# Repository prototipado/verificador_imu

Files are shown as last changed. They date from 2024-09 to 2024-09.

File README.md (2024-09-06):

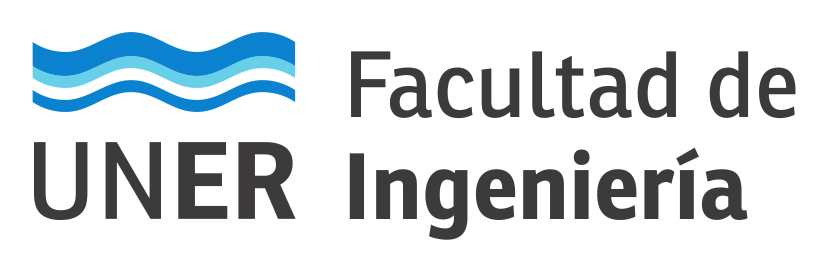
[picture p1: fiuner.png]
Scheme|30%


# Verificación de IMUs

En este repositorio se encuentran los archivos de diseño para un dispositivo destinado a la verificación de IMUs. El diseño se basa en el [Cubo de Calibración](https://github.com/xioTechnologies/Calibration-Cube) propuesto por Madgwick, pero en este caso no se utiliza para calibración, sino para verificar los valores de orientación espacial generados por una IMU a partir de la fusión de datos de sensores inerciales y/o magnetómetros.

El dispositivo tiene dos variantes, una de ellas utilizada para verificaciones estáticas, donde la plataforma se mueve de manera manual siguiendo posiciones preestablecidas cada 5º.

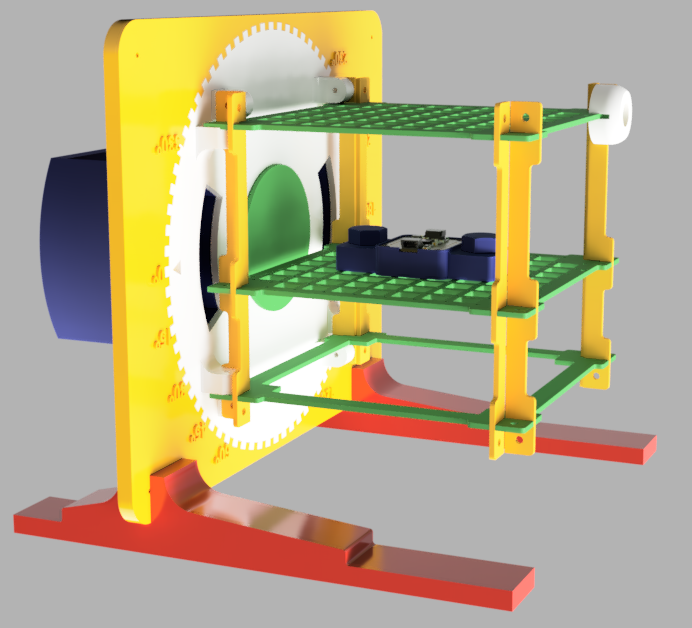
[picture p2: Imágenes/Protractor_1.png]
protractor


Y otra variante donde se monta sobre un servo (MG996R) para verificaciones dinámicas, asistidas por análisis de video.

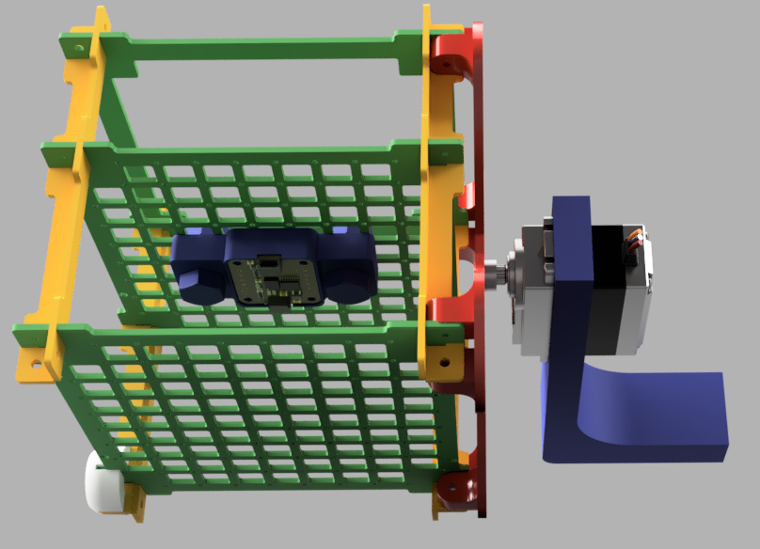
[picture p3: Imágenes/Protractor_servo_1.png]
protractor_servo


## Implementación

El diseño esta pensado para ser impreso en 3D, para la versión estática es necesario imprimir:

| Parte | Cantidad |
| :--- | ---: |
| base | 1 |
| base_completa | 2 |
| pata | 2 |
| tirante | 8 |
| protractor | 1 |
| rotor | 1 |
| pata | 2 |
| tuerca | 1 |
| soporte_elastico  | 1 |
| tornillo | 1 |

El **tornillo** mantiene el **rotor** contra el **protractor** mediante la **tuerca**, la cual cuenta con un par de canales por los cuales pasar una banda elástica que va sujeta finalmente al **soporte_elastico**. La tensión ejercida por la banda es la suficiente para mantener el **rotor** en su lugar, pero permite que facilmente pueda ser retirado para modificar la posición angular.

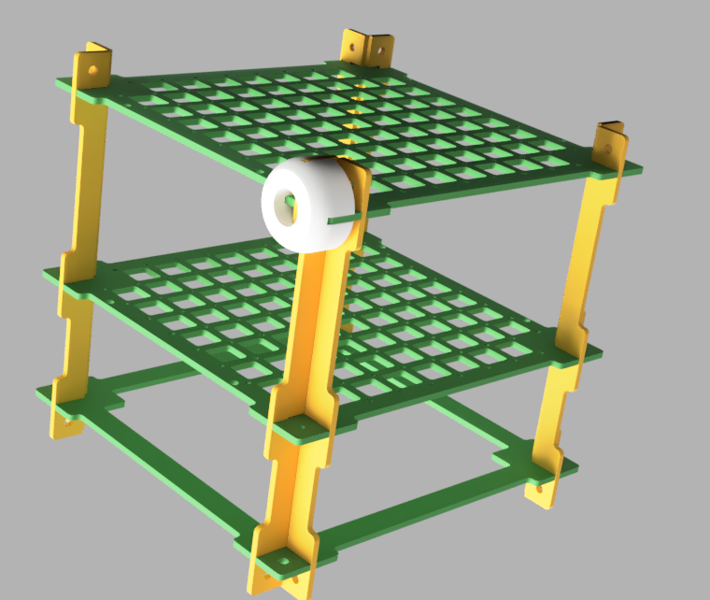
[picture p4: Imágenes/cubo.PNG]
cubo

El cubo se ensambla como se muestra en la imágen superior. Las piezas se sostienen por la misma fricción de las piezas plásticas.

La fijación del cubo al rotor se realiza con tornillos plásticos M2. La utilización de plástico para toda la construcción intenta minimizar la presencia de materiales ferromagnéticos que puedan afectar las mediciones del magnetómetro.

Para la versión dinámica es necesario imprimir:

| Parte | Cantidad |
| :--- | ---: |
| rotor_servo | 1 |
| soporte_servo | 1 |
| marker | 3 |

En este caso el cubo de calibración se monta en el **rotor_servo** y este a su vez a un servo. Los marcadores se pueden colocar en las esquinas del cubo para facilitar el trackeo de los movimientos mediante el uso de Software.

Tanto las **patas** de la versión estática como el **soporte_servo** de la dinámica pueden ser sujetas mediante [clamps](https://www.thingiverse.com/thing:1673030).

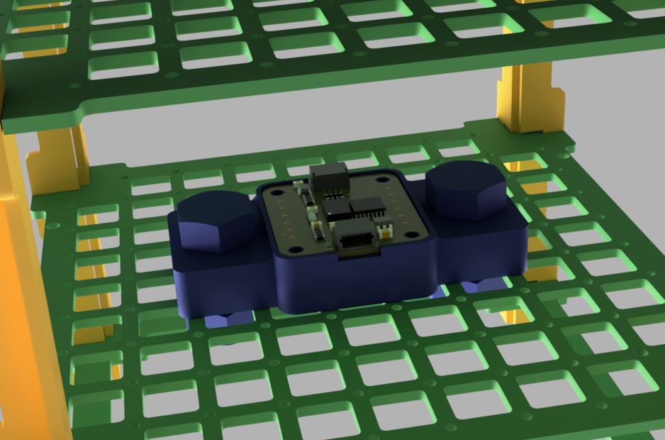
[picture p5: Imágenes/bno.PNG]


Se adjunta además un soporte impreso (**bno08x_holder**) para una módulo [BNO085 de Adafruit](https://www.adafruit.com/product/4754) y un par tornillo-tuerca (**m5-nut-105**/**m5-screw-95**) para la sujeción del soporte al cubo de calibración. El montaje de la placa al soporte se realiza también con tornillos M2 plásticos.

## Electrónica

Se adjunta además los [fuentes](./Firmware) utilizados para levantar los datos. Por un lado el firmware de una placa ESP32-S2 de Adafruit conectada al BNO085 para el envío de datos a la PC. Por otro lado el firmware de un Arduino Uno, el cual controla los movimientos del servo y habilita la transmisión de datos del BNO a la PC. El ESP32 enciende un led al inicio del envío de datos y todo el proceso comienza al presionar un pulsador conectado al Aruino Uno. Todo esto tiene como propósito simplificar el procesos de captura de datos, mantener consistencia entre los ensayos y facilitar la sincronización de los datos recabados.

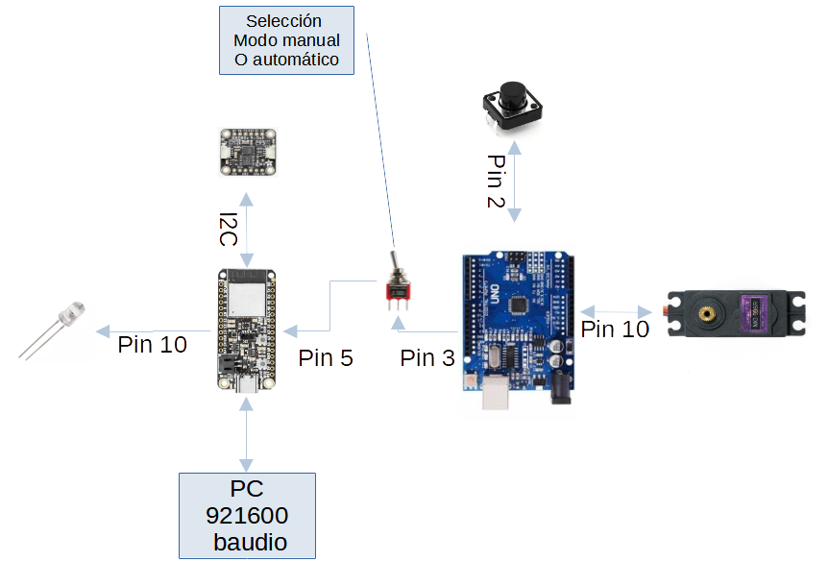
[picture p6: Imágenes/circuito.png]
circuito


A continuación se muestraa a modo de ejemplo una captura del análisis de datos para rotaciones alrededor del eje y. Los datos de del tracker se obtuvieron a partir de análisis de video utilizando el software [Tracker](https://physlets.org/tracker/). 

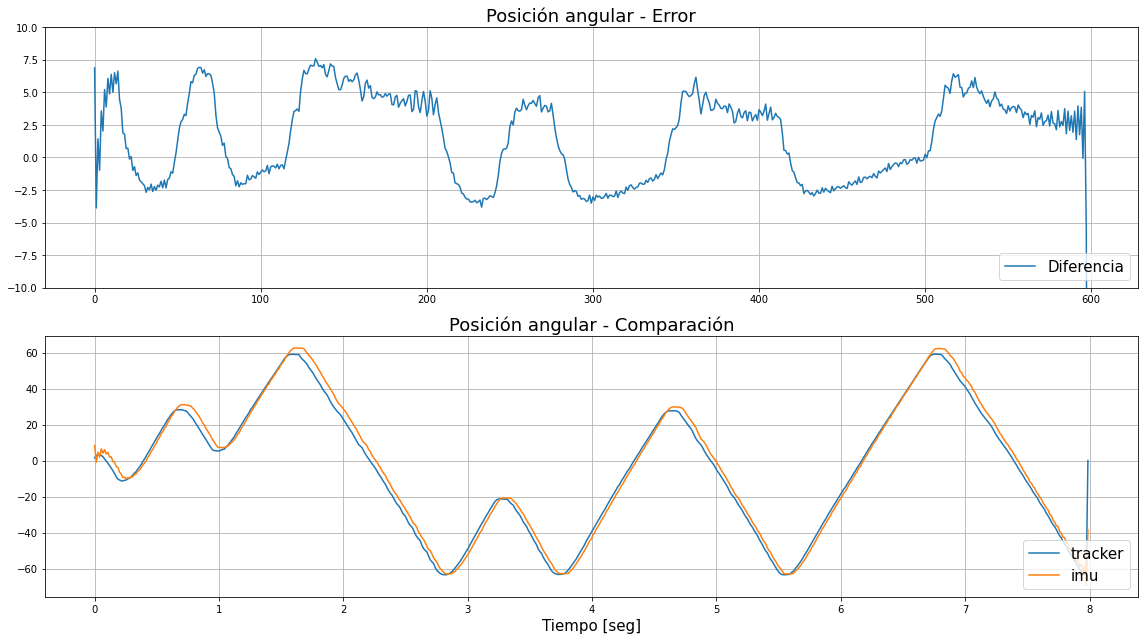
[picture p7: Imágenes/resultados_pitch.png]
resultados_pitch


Setup utilizado, para yaw (a la izq.), y pitch y roll a la derecha. Para el video se utilizó una Webcam PlayStation Eye capaz de tomar video hasta 187 FPS.

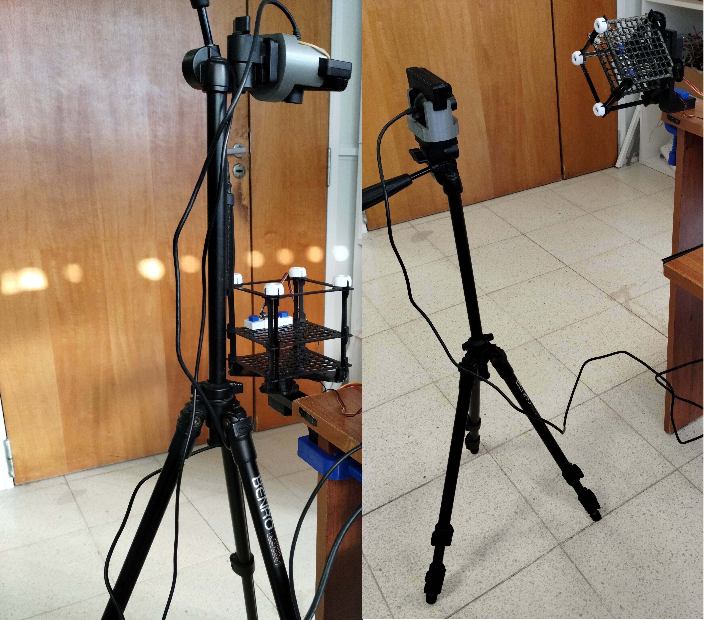
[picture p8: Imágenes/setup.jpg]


## Autores

* Juan Ignacio Cerrudo (juan.cerrudo@uner.edu.ar)

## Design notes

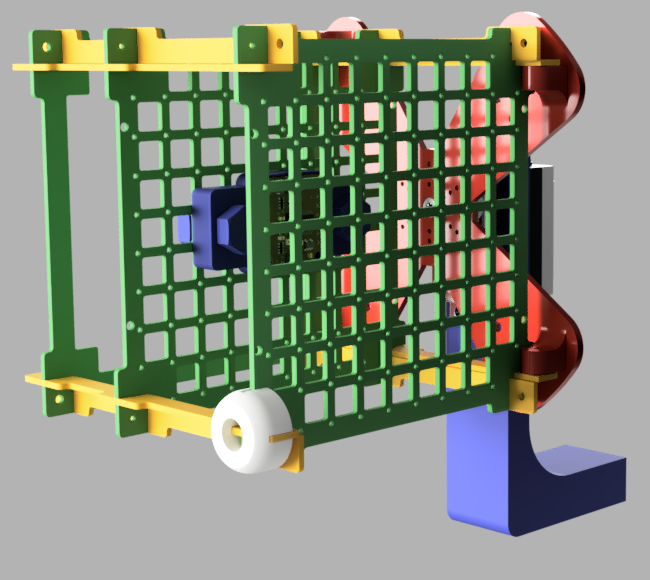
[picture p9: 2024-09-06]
Imágenes/Protractor_servo_2.png

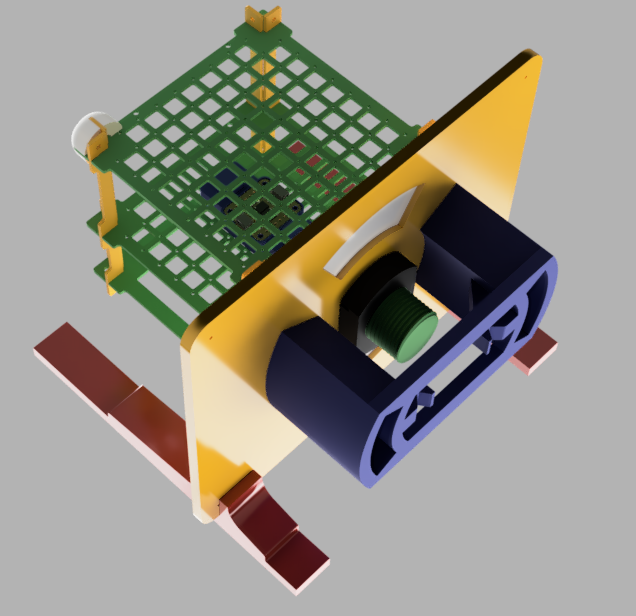
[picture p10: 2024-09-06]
Imágenes/Protractor_2.png

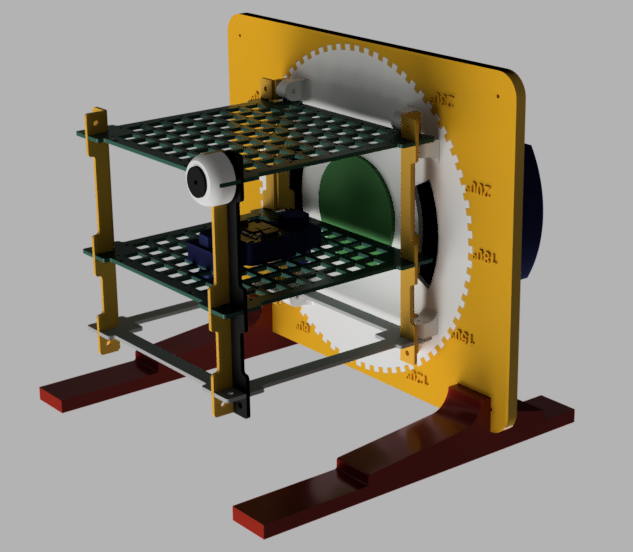
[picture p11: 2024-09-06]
Imágenes/Protractor_3.png

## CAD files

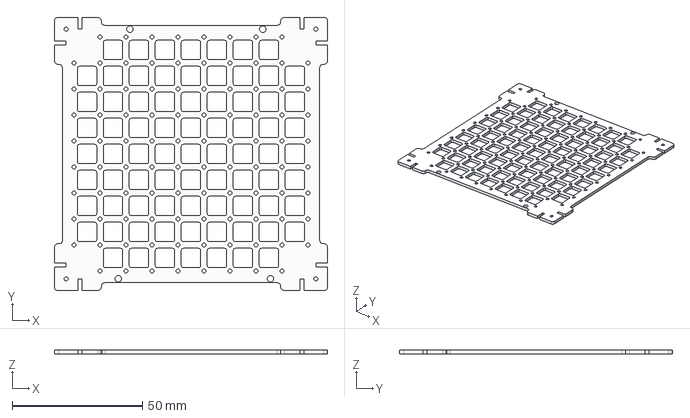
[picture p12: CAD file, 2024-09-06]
STEPs/base_completa v5.step
104.8 x 104.8 x 1.60 mm

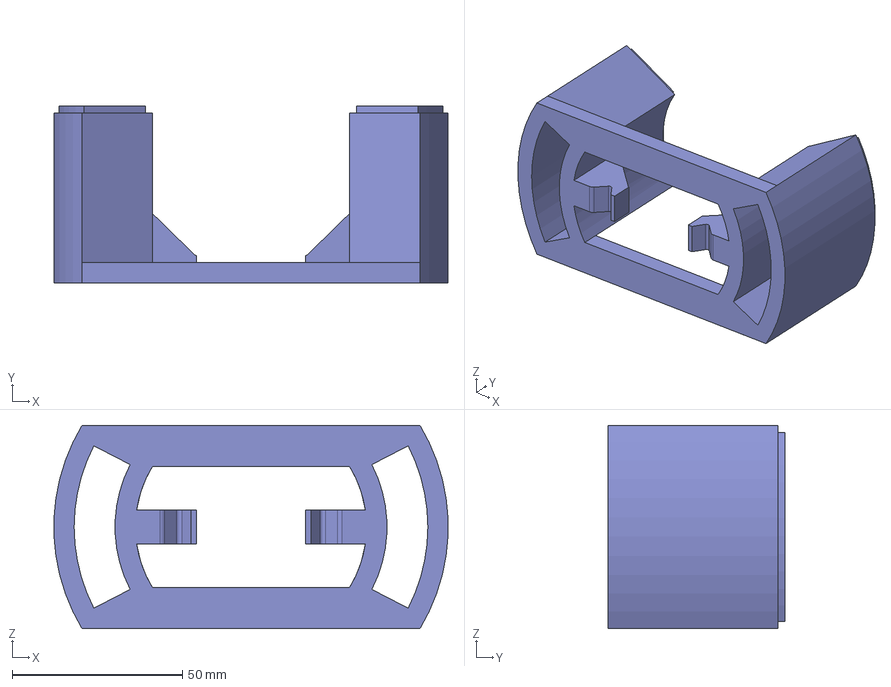
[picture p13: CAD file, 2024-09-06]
STEPs/soporte_elastico.step
115.9 x 52.0 x 59.7 mm

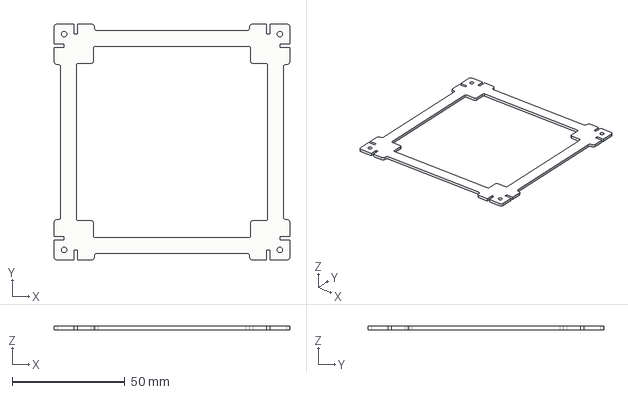
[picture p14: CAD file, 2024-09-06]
STEPs/base v3.step
104.8 x 104.8 x 1.60 mm

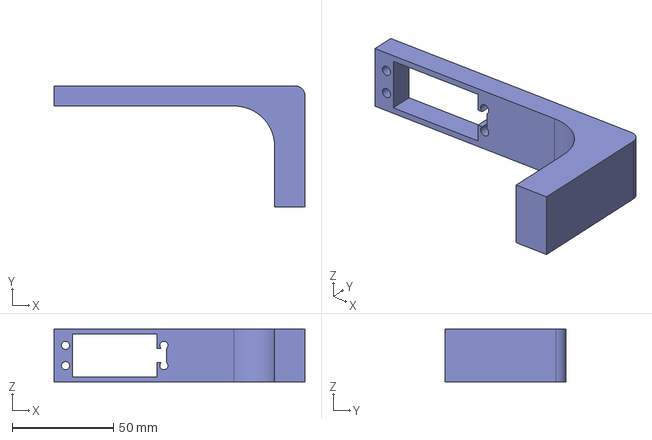
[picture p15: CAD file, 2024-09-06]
STEPs/soporte_servo.step
124.0 x 60.0 x 26.0 mm

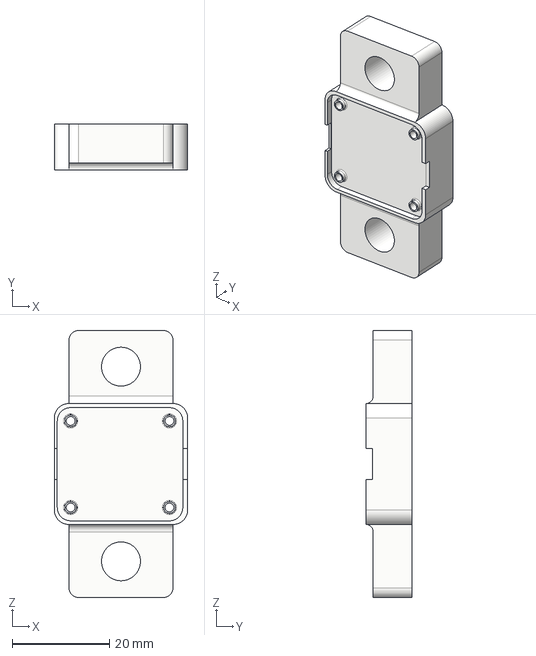
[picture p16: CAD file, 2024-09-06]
STEPs/bno08x_holder v6.step
27.4 x 9.50 x 54.9 mm

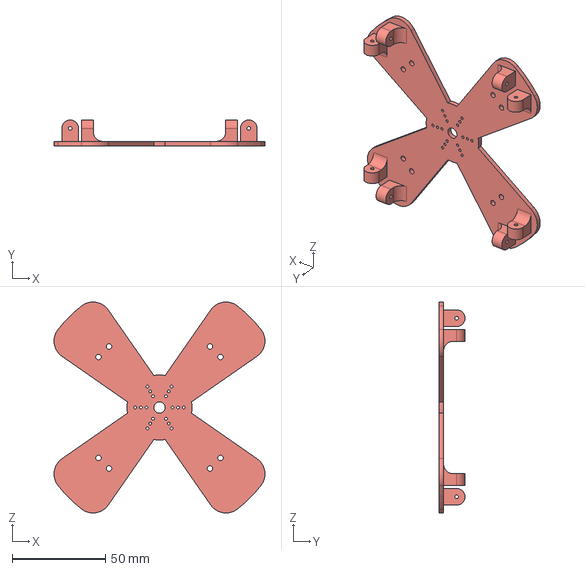
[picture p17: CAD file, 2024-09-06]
STEPs/rotor_servo.step
113.4 x 14.0 x 113.4 mm

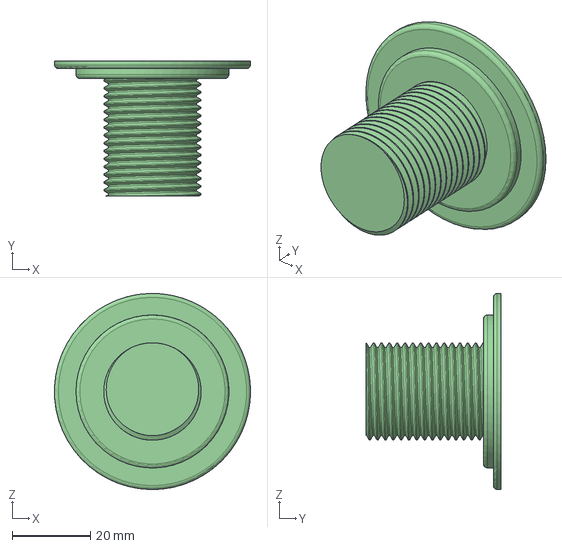
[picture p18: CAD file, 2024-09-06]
STEPs/tornillo.step
50.0 x 34.5 x 50.0 mm

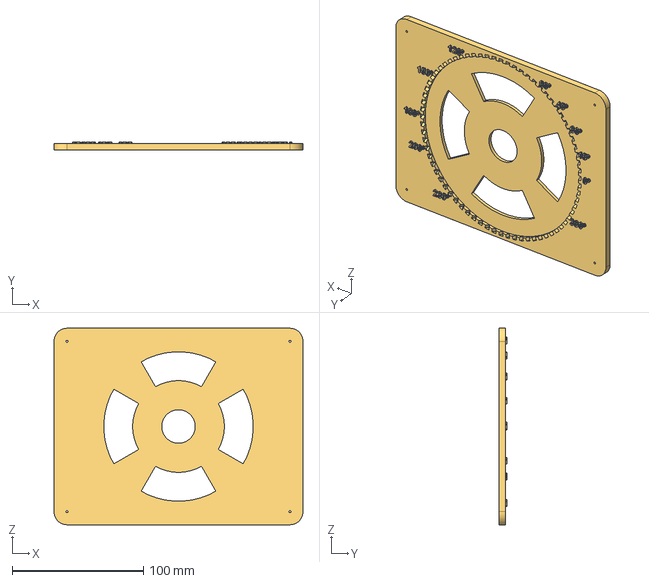
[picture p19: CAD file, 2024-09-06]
STEPs/protractor.step
190.0 x 6.00 x 150.0 mm

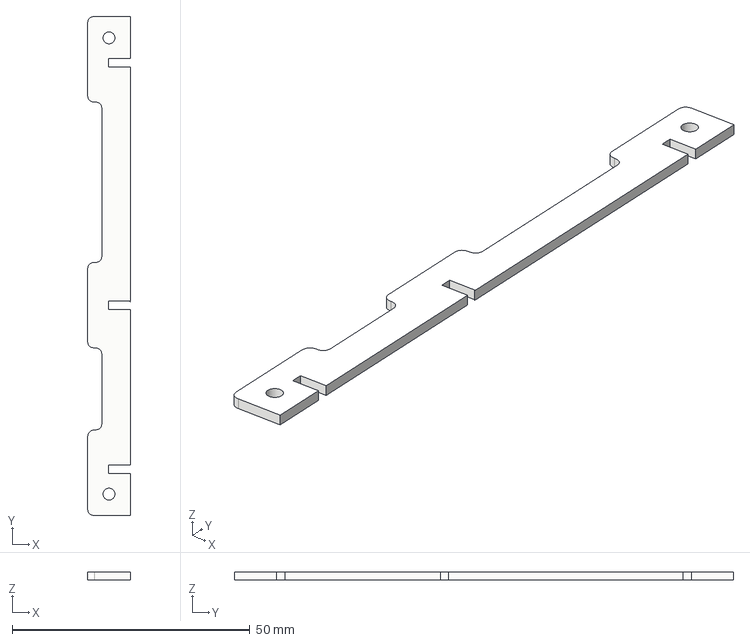
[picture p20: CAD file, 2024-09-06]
STEPs/tirante v5.step
8.99 x 104.8 x 1.60 mm

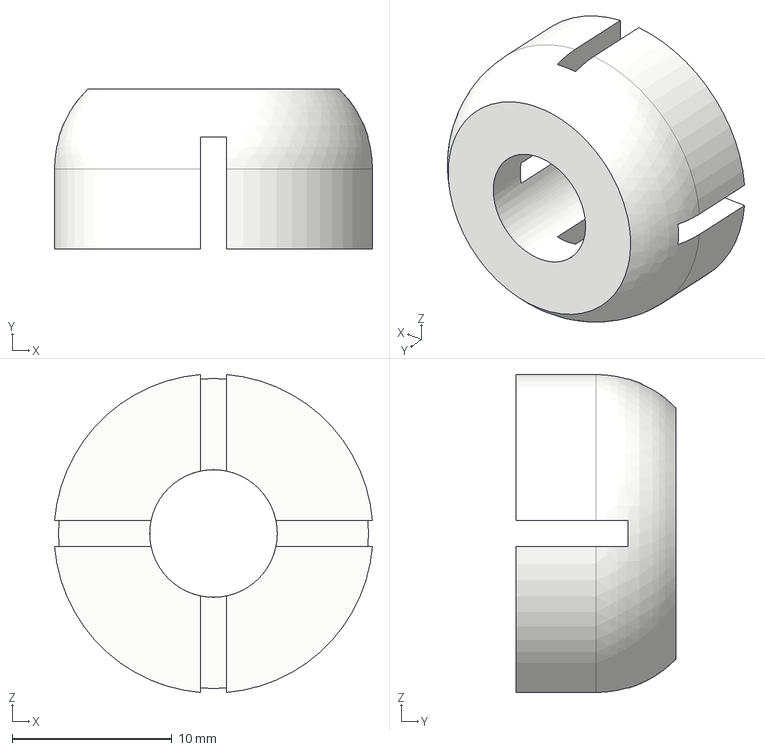
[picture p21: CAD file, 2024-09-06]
STEPs/marker v7.step
19.9 x 10.0 x 19.9 mm

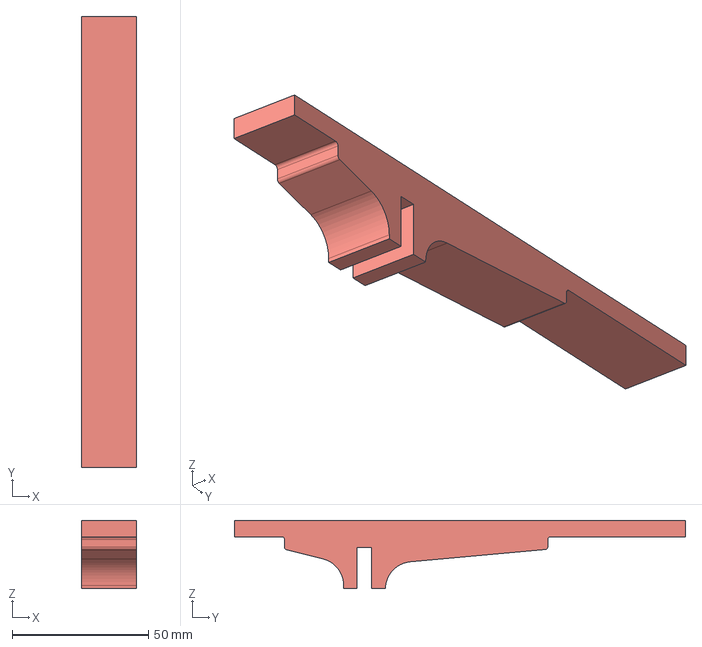
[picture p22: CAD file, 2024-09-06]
STEPs/pata.step
20.0 x 165.4 x 25.0 mm

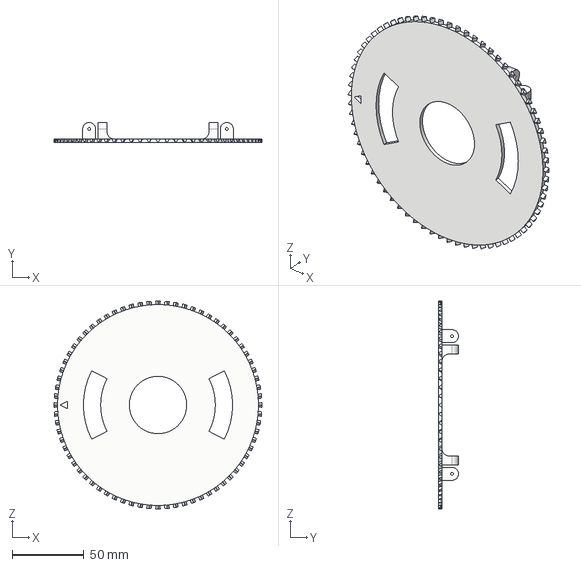
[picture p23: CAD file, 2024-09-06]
STEPs/rotor.step
145.0 x 14.0 x 145.0 mm

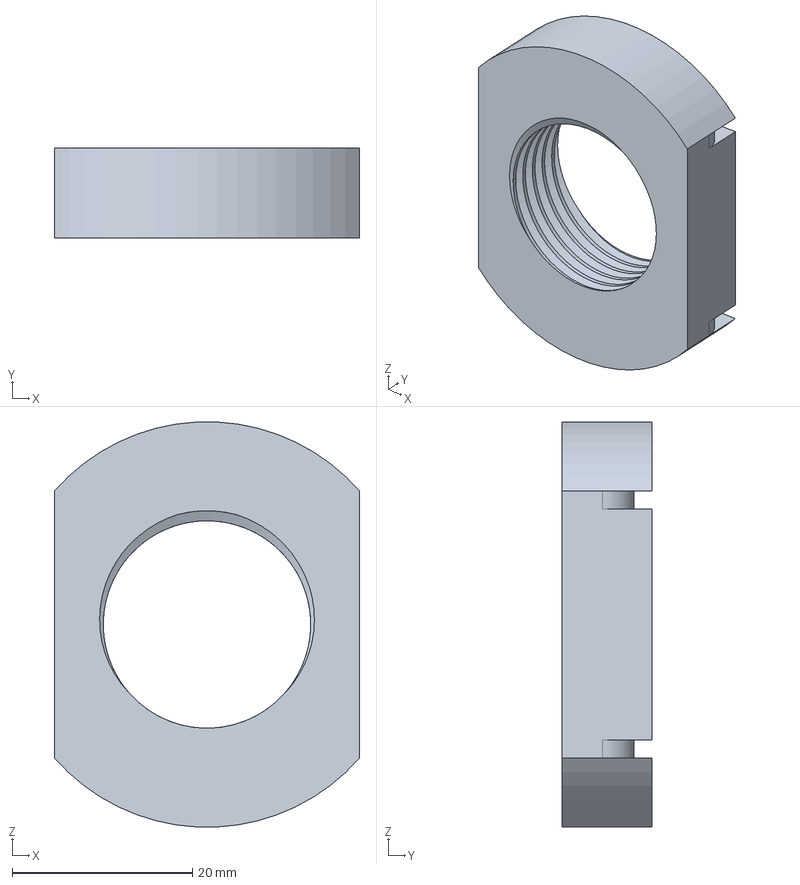
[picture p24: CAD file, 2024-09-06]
STEPs/tuerca.step
33.9 x 10.0 x 44.9 mm

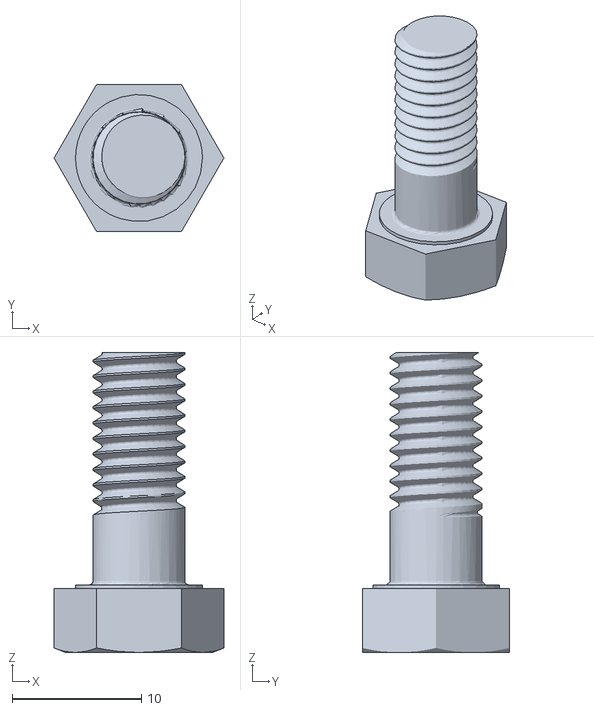
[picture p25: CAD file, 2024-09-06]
STLs/m5-screw-95 v5.stl
13.2 x 11.4 x 23.2

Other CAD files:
STLs/m5-nut-105 v2.stl
STLs/base v3.stl
STLs/base_completa v5.stl
STLs/bno08x_holder v6.stl
STLs/marker v7.stl
STLs/pata.stl
STLs/protractor.stl
STLs/rotor.stl
STLs/rotor_servo.stl
STLs/soporte_elastico.stl
STLs/soporte_servo.stl
STLs/tirante v5.stl
STLs/tornillo.stl
STLs/tuerca.stl

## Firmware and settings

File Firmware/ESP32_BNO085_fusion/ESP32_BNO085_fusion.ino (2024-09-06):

/*
  Using the BNO080 IMU
  By: Nathan Seidle
  SparkFun Electronics
  Date: December 21st, 2017
  SparkFun code, firmware, and software is released under the MIT License.
  Please see LICENSE.md for further details.

  Feel like supporting our work? Buy a board from SparkFun!
  https://www.sparkfun.com/products/14586

  This example shows how to output the i/j/k/real parts of the rotation vector.
  https://en.wikipedia.org/wiki/Quaternions_and_spatial_rotation

  It takes about 1ms at 400kHz I2C to read a record from the sensor, but we are polling the sensor continually
  between updates from the sensor. Use the interrupt pin on the BNO080 breakout to avoid polling.

  Hardware Connections:
  Attach the Qwiic Shield to your Arduino/Photon/ESP32 or other
  Plug the sensor onto the shield
  Serial.print it out at 115200 baud to serial monitor.
*/

#include <Wire.h>

#include "SparkFun_BNO08x_Arduino_Library.h" // Click here to get the library: http://librarymanager/All#SparkFun_BNO080
BNO08x myIMU1; //Open I2C ADR jumper - goes to address 0x4B
BNO08x myIMU2; //Closed I2C ADR jumper - goes to address 0x4A

const byte interruptPin = 5;
const byte ledPin = 10;

hw_timer_t * timer = NULL;
volatile SemaphoreHandle_t timerSemaphore;
portMUX_TYPE timerMux = portMUX_INITIALIZER_UNLOCKED;
volatile uint32_t lastIsrAt = 0;

void ARDUINO_ISR_ATTR onTimer(){
  // Increment the counter and set the time of ISR
  
  portENTER_CRITICAL_ISR(&timerMux);
  lastIsrAt = micros();
  portEXIT_CRITICAL_ISR(&timerMux);
  
  // Give a semaphore that we can check in the loop
  xSemaphoreGiveFromISR(timerSemaphore, NULL);
  // It is safe to use digitalRead/Write here if you want to toggle an output
}


void setup()
{
  Serial.begin(921600);
  while (!Serial) delay(20);    // wait until serial monitor opens
  Serial.println();

  Wire.begin();
  Wire.setClock(400000); //Increase I2C data rate to 400kHz
 
  
  //When a large amount of time has passed since we last polled the sensors
  //they can freeze up. To un-freeze it is easiest to power cycle the sensor.
  pinMode(interruptPin, INPUT_PULLDOWN);
   pinMode(ledPin, OUTPUT);
  //Start 2 sensors
  if (myIMU1.begin(0x4A) == false)
  {
    Serial.println("First BNO080 not detected with I2C ADR jumper open. Check your jumpers and the hookup guide. Freezing...");
    //while(1);
  }


  setReports();

  // Create semaphore to inform us when the timer has fired
  timerSemaphore = xSemaphoreCreateBinary();

  // Set timer frequency to 1Mhz
  timer = timerBegin(1000000);

  // Attach onTimer function to our timer.
  timerAttachInterrupt(timer, &onTimer);

  // Set alarm to call onTimer function every second (value in microseconds).
  // Repeat the alarm (third parameter) with unlimited count = 0 (fourth parameter).
  timerAlarm(timer, 8000, true, 0);
}

// Here is where you define the sensor outputs you want to receive
void setReports(void) {
  Serial.println("Setting desired reports");
  if (myIMU1.enableRotationVector(5) == true) {
    Serial.println(F("Rotation vector enabled"));
    Serial.println(F("Output in form roll, pitch, yaw"));
  } else {
    Serial.println("Could not enable rotation vector");
  }/*
  if (myIMU1.enableGyro() == true) {
    Serial.println(F("Gyro enabled"));
    Serial.println(F("Output in form x, y, z, in radians per second"));
  } else {
    Serial.println("Could not enable gyro");
  }*/
}

void loop()
{
 

  if (myIMU1.wasReset()) {
    Serial.print("sensor was reset ");
    setReports();
  }
   digitalWrite(ledPin, 1);
  // Has a new event come in on the Sensor Hub Bus?

  if (xSemaphoreTake(timerSemaphore, 0) == pdTRUE){
    if (myIMU1.getSensorEvent() == true && (digitalRead(interruptPin))) {
      digitalWrite(ledPin, 0);

      // is it the correct sensor data we want?
      if (myIMU1.getSensorEventID() == SENSOR_REPORTID_ROTATION_VECTOR) {
      //if (myIMU1.getSensorEventID() == SENSOR_REPORTID_GYROSCOPE_CALIBRATED) {
  
    
      float roll = (myIMU1.getRoll()) * 180.0 / PI; // Convert roll to degrees
      float pitch = (myIMU1.getPitch()) * 180.0 / PI; // Convert pitch to degrees
      float yaw = (myIMU1.getYaw()) * 180.0 / PI; // Convert yaw / heading to degrees
      float quatI = myIMU1.getQuatI();
      float quatJ = myIMU1.getQuatJ();
      float quatK = myIMU1.getQuatK();
      float quatReal = myIMU1.getQuatReal();
      //Serial.print("A");
      //Serial.print(",");
      Serial.print(lastIsrAt);
      Serial.print(",");
      Serial.print(quatI, 2);
      Serial.print(F(","));
      Serial.print(quatJ, 2);
      Serial.print(F(","));
      Serial.print(quatK, 2);
      Serial.print(F(","));
      Serial.print(quatReal, 2);
      Serial.print(F(","));
      Serial.print(roll, 2);
      Serial.print(F(","));
      Serial.print(pitch, 2);
      Serial.print(F(","));
      Serial.print(yaw, 2);
      //Serial.print("\n");
      Serial.println();
      /*
        float x = myIMU1.getGyroX()*57.32;
      float y = myIMU1.getGyroY()*57.32;
      float z = myIMU1.getGyroZ()*57.32;

      Serial.print(x, 2);
      Serial.print(F(","));
      Serial.print(y, 2);
      Serial.print(F(","));
      Serial.print(z, 2);
      Serial.println();*/
      }
    }
  }
}

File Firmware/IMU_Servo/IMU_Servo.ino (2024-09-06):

/*
|| @author         Brett Hagman <bhagman@wiring.org.co>
|| @url            http://wiring.org.co/
||
|| @description
|| |
|| | This is an example sketch using the ControlledServo library to control a TinkerKit Braccio
|| | (servo controlled robotic arm).
|| |
|| #
||
|| @license Please see the accompanying LICENSE.txt file for this project.
||
*/

#include "ControlledServo.h"
#include <Servo.h>
#include <arduino.h>

Servo s_shoulder;


const int shoulderPin = 10;

uint8_t angles_1[13] = {60,45,60,90,60,120,0,45,0,90,0,120,0};
uint8_t angles_2[7] = {0,60,120,60,120,0};
uint8_t angles_3[7] = {0,30,60,90,120,0};
uint8_t * angles;
int angleRate = 10; // in msPerDegree
int seq=0;
int speed=0;
ControlledServo shoulder;
bool move = false;

unsigned long pressedTime  = 0;
unsigned long releasedTime = 0;

/*
|| Set all servos to a given angle.  All parameters required.
*/
void setAll(uint8_t shoulderAngle)
{
  shoulder.moveTo(shoulderAngle);
}


/*
|| Checks if any joint is moving.
*/
boolean moving()
{
  boolean result;
  result = shoulder.moving();
  return result;
}


/*
|| Updates all servos. Can be used to asynchronously control the servos.
*/
bool update()
{
  bool processing = false;
  processing = shoulder.update();
  return processing;
}

const byte interruptPin = 2;
const byte outPin = 3;
void setup()
{
  unsigned long myTime = millis();
  Serial.begin(9600);
  Serial.println(F("Calibration Cube"));

  s_shoulder.attach(shoulderPin);
  shoulder.setServo(s_shoulder);
  // Set angle change rates
  shoulder.setRate(20);

  pinMode(interruptPin, INPUT_PULLUP);
  pinMode(outPin, OUTPUT);
  attachInterrupt(digitalPinToInterrupt(interruptPin), blink, CHANGE);
  pinMode(LED_BUILTIN, OUTPUT);
  angles=angles_1;

  Serial.print(F("Going to start position..."));
  setAll(0);
  while (moving())
    update();
  setAll(120);
  while (moving())
    update();
  setAll(60);
  while (moving())
    update();  
  Serial.println(F("Done"));
  

  Serial.println(myTime); // prints time since program started
}


void loop()
{
  if(move){
    sequence();
  }
}

void blink() {
  Serial.println("Button pressed...");
 pressedTime = 0;
 while(!digitalRead(interruptPin)){
 pressedTime++;

  Serial.println(pressedTime-0);
  if(((pressedTime-0) > 100)  && (pressedTime-0 < 120)){
      //Serial.println("Change angleRate...");
      digitalWrite(LED_BUILTIN, LOW);
      delay(200);
      digitalWrite(LED_BUILTIN, HIGH);
      delay(200);
      digitalWrite(LED_BUILTIN, LOW);
      delay(200);
      digitalWrite(LED_BUILTIN, HIGH);
      delay(200);
      digitalWrite(LED_BUILTIN, LOW);  
    }
   if(((pressedTime-0) > 300)  && ((pressedTime-0) < 350)){
      //Serial.println("Change angle seq...");
      digitalWrite(LED_BUILTIN, LOW);
      delay(400);
      digitalWrite(LED_BUILTIN, HIGH);
      delay(400);
      digitalWrite(LED_BUILTIN, LOW);
      delay(400);
      digitalWrite(LED_BUILTIN, HIGH);
      delay(400);
      digitalWrite(LED_BUILTIN, LOW);   
    }
  }

  
 releasedTime = millis();

 long pressDuration = pressedTime;
 if((pressDuration>100) && (pressDuration<120)){
   //INCREASE SPEED
   speed++;
   switch(speed){
    case 1:
      angleRate=10;
      Serial.print(F("angleRate=5..."));
      break;
    case 2:
      angleRate=10;
      Serial.print(F("angleRate=10..."));
      break;
    case 3:
      angleRate=10;
      Serial.print(F("angleRate=20..."));
      speed=0;
      break;
   }
  }
 if(pressDuration<50){
  //START TEST
  move = true;
  } 
if(pressDuration>350){
   //CHANGE POROFILE
   seq++;
   switch(seq){
    case 1:
      angles=angles_1;
      Serial.print(F("angles_1..."));
      break;
    case 2:
      angles=angles_1;
      Serial.print(F("angles_2..."));
      break;
    case 3:
      angles=angles_1;
      Serial.print(F("angles_3..."));
      seq=0;
      break;
   }
  }
}

void sequence(void){
  //Serial.print(F("Position 1..."));
  digitalWrite(outPin, HIGH);
  shoulder.setRate(angleRate);
  for(int i=0;i<14;i++){
  //  if(i==6)
  //    shoulder.setRate(5);
    setAll(angles[i]);
    while (moving())
      update();
    //Serial.print(F("Position 2..."));
  }
  digitalWrite(outPin, LOW);
  delay(3000);
  Serial.print(F("Going to start position..."));
  shoulder.setRate(20);
  setAll(60);
    while (moving())
      update();
  move = false;
  digitalWrite(outPin, LOW);
}

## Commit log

2024-09-06 Commit inicial del repositorio incluyendo archivo README, modelos 3D en formato STEP y STL y codigo fuente de firmware para ESP32 y Arduno.
    [base v3.step, base v3.stl, base_completa v5.step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]
2024-09-06 Se modifica archivo README para mostrar correctamente imágenes.
